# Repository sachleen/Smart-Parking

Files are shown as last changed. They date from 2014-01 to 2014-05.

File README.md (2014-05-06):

Smart Parking ([GitHub][1])
=============

A system to monitor parking space availability and help drivers quickly find a nearby place to park.

[California State University, Sacramento][2]

Computer Engineering Senior Design Project

Team #4

 - Sachleen Sandhu
 - Caleb Fountain
 - Phillip Booker

  [1]: https://github.com/sachleen/Smart-Parking
  [2]: http://csus.edu

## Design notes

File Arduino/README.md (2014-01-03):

Base
====

Base station is responsible for communicating data from the wireless nodes to the web server

Node
====

Each wireless node connects up to 32 parking sensors. The node transmits the status of the sensors to the base.

Sensor
======

A parking sensor detects the presence of a vehicle and sends its status to the node.

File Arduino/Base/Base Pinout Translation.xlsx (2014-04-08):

Pin Names | AKA | Arduino Chip Pins | Arduino SMT Pins | Connected to Base Station Code
Reset |  | 1 | 29 | RST(PropPlug, I2C)
(RXD)PD0 | Digital Pin 0 (RX) | 2 | 30 | TX(PropPlug)
(TXD)PD1 | Digital Pin 1 (TX) | 3 | 31 | RX(PropPlug)
(INT0)PD2 | Digital Pin 2 | 4 | 32 | SIM900_PWR
(INT1)PD3 | Digital Pin 3 | 5 | 1 | SIM900_RST
(T0)PD4 | Digital Pin 4 | 6 | 2 | XBEE_DTR(Sleep Pin)
VCC |  | 7 | 4,6 | VCC from MCP73833 Charing Chip
GND |  | 8 | 3,5 | Regular GND
XTAL1 |  | 9 | 7 | Resonator
XTAL2 |  | 10 | 8 | Resonator
(T1)PD5 | Digital Pin 5 | 11 | 9 | XBEE_DOUT
(AIN0)PD6 | Digital Pin 6 | 12 | 10 | XBEE_DIN
(AIN1)PD7 | Digital Pin 7 | 13 | 11 | SIM900_RX
(ICP)PB0 | Digital Pin 8 | 14 | 12 | SIM900_TX
(OC1)PB1 | Digital Pin 9 | 15 | 13
(SS)PB2 | Digital Pin 10 | 16 | 14
(MOSI)PB3 | Digital Pin 11 | 17 | 15 | I2C(MOSI)
(MISO)PB4 | Digital Pin 12 | 18 | 16 | I2C(MISO)
(SCK)PB5 | Digital Pin 13 | 19 | 17 | I2C(SCK)
AVCC |  | 20 | 18 | VCC from MCP73833 Charing Chip
AREF |  | 21 | 20 | VCC from MCP73833 Charing Chip
AGND |  | 22 | 21 | Regular GND
(ADC0)PC0 | Analog Input 0 | 23 | 23
(ADC1)PC1 | Analog Input 1 | 24 | 24
(ADC2)PC2 | Analog Input 2 | 25 | 25
(ADC3)PC3 | Analog Input 3 | 26 | 26
(ADC4)PC4 | Analog Input 4 | 27 | 27
(ADC5)PC5 | Analog Input 5 | 28 | 28
ADC6 | Analog Input 6 |  | 19
ADC7 | Analog Input 7 |  | 22

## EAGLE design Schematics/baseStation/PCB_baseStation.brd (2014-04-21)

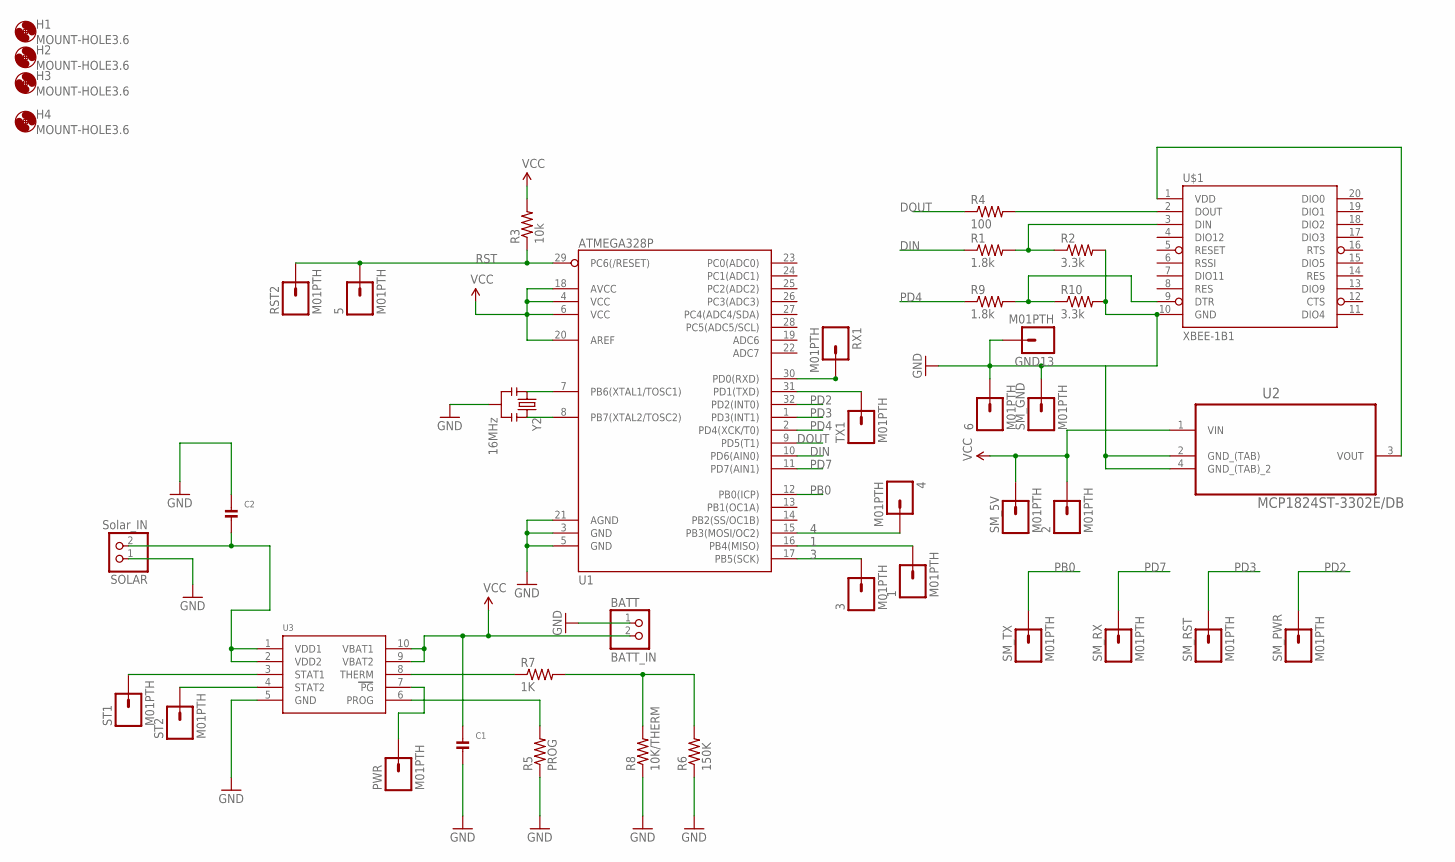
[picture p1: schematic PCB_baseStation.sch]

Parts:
1, 2, 3, 4, 5, 6: M01PTH; 1X01
BATT: BATT_IN; JSTPH2
C1, C2: CAP_CERAMIC0805; 0805
GND13: M01PTH; 1X01
H1, H2, H3, H4: MOUNT-HOLE3.6; 3,6
PWR: M01PTH; 1X01
R1, R9: 1.8k; 0603-RES
R2, R10: 3.3k; 0603-RES
R3: 10k; 1206
R4: 100; 0603-RES
R5: PROG; 0805-THM
R6: 150K; M0805
R7: 1K; M0805
R8: 10K/THERM; 0805-THM
RST2: M01PTH; 1X01
RX1: M01PTH; 1X01
SM_5V: M01PTH; 1X01
SM_GND: M01PTH; 1X01
SM_PWR: M01PTH; 1X01
SM_RST: M01PTH; 1X01
SM_RX: M01PTH; 1X01
SM_TX: M01PTH; 1X01
SOLAR: Solar_IN; JSTPH2
ST1, ST2: M01PTH; 1X01
TX1: M01PTH; 1X01
U1: ATMEGA328P; TQFP32-08
U2: MCP1824ST-3302E/DB; SOT230P700X180-4N
U3: MCP73833; MSOP10
U$1: XBEE-1B1; XBEE-1
Y2: 16MHz; RESONATOR-SMD

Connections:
1: 1.1, U1.16 (PB4(MISO))
3: 3.1, U1.17 (PB5(SCK))
4: 4.1, U1.15 (PB3(MOSI/OC2))
DIN: R1.1, U1.10 (PD6(AIN0))
DOUT: R4.1, U1.9 (PD5(T1))
GND: 6.1, BATT.1, C1.2, C2.1, GND13.1, R2.2, R5.1, R6.1, R8.1, R10.2, SM_GND.1, SOLAR.1, U1.3 (GND), U1.5 (GND), U1.21 (AGND), U2.2 (GND_(TAB)), U2.4 (GND_(TAB)_2), U3.5 (GND), U$1.10 (GND), Y2.2
unnamed: ST1.1, U3.3 (STAT1)
unnamed: ST2.1, U3.4 (STAT2)
unnamed: R1.2, R2.1, U$1.3 (DIN)
unnamed: R4.2, U$1.2 (DOUT)
unnamed: R9.2, R10.1, U$1.9 (DTR)
unnamed: U1.7 (PB6(XTAL1/TOSC1)), Y2.1
unnamed: U1.8 (PB7(XTAL2/TOSC2)), Y2.3
unnamed: C2.2, SOLAR.2, U3.1 (VDD1), U3.2 (VDD2)
unnamed: R5.2, U3.6 (PROG)
unnamed: PWR.1, U3.7 (PG)
unnamed: R6.2, R7.2, R8.2
unnamed: U2.3 (VOUT), U$1.1 (VDD)
unnamed: R7.1, U3.8 (THERM)
unnamed: TX1.1, U1.31 (PD1(TXD))
unnamed: RX1.1, U1.30 (PD0(RXD))
PB0: SM_TX.1, U1.12 (PB0(ICP))
PD2: SM_PWR.1, U1.32 (PD2(INT0))
PD3: SM_RST.1, U1.1 (PD3(INT1))
PD4: R9.1, U1.2 (PD4(XCK/T0))
PD7: SM_RX.1, U1.11 (PD7(AIN1))
RST: 5.1, R3.1, RST2.1, U1.29 (PC6(/RESET))
VCC: 2.1, BATT.2, C1.1, R3.2, SM_5V.1, U1.4 (VCC), U1.6 (VCC), U1.18 (AVCC), U1.20 (AREF), U2.1 (VIN), U3.9 (VBAT2), U3.10 (VBAT1)

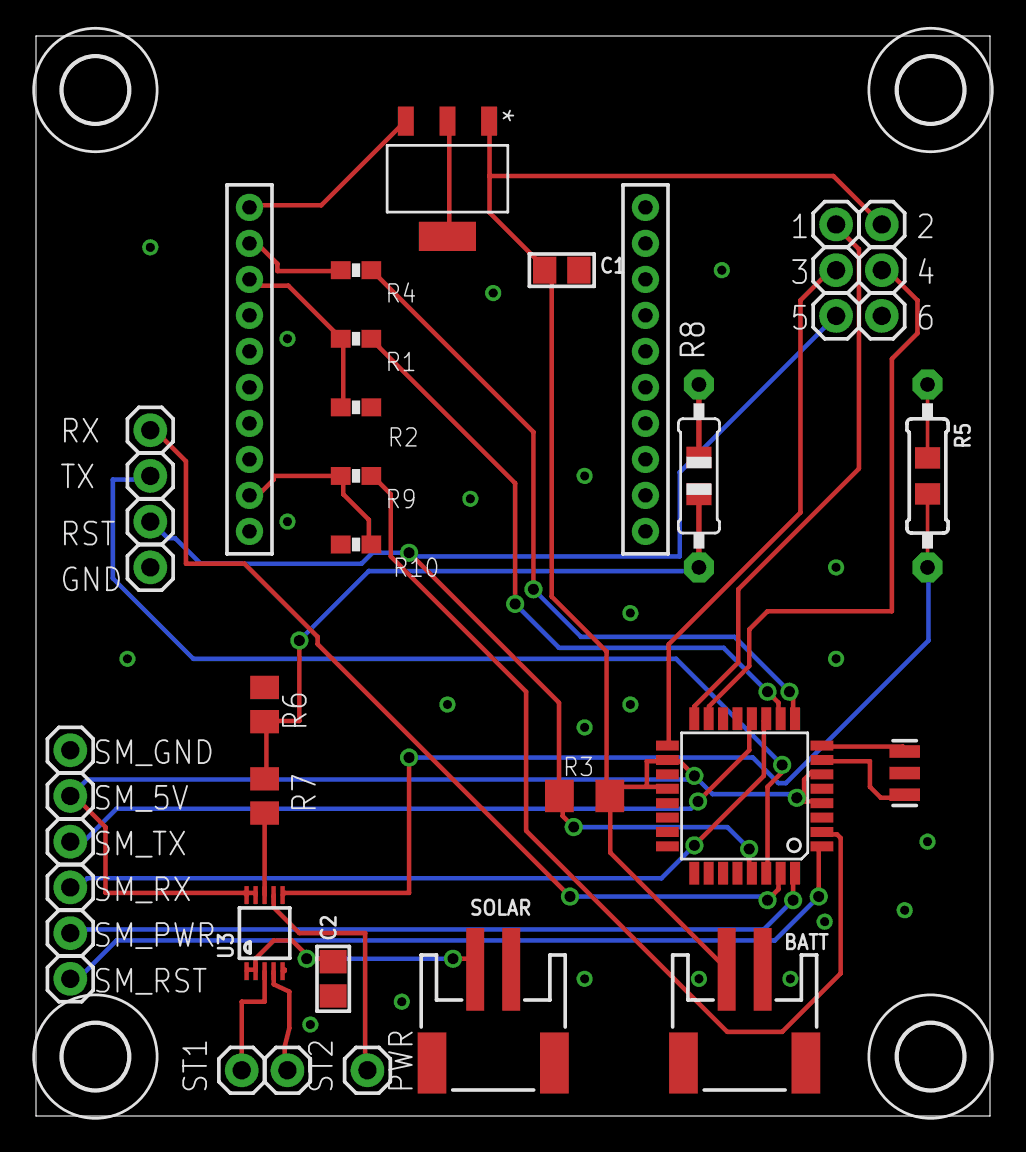
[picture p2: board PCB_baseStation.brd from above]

Board: 2 copper layers, 53.0 x 60.0 mm, 42 parts (0 on the bottom side), 28 nets.

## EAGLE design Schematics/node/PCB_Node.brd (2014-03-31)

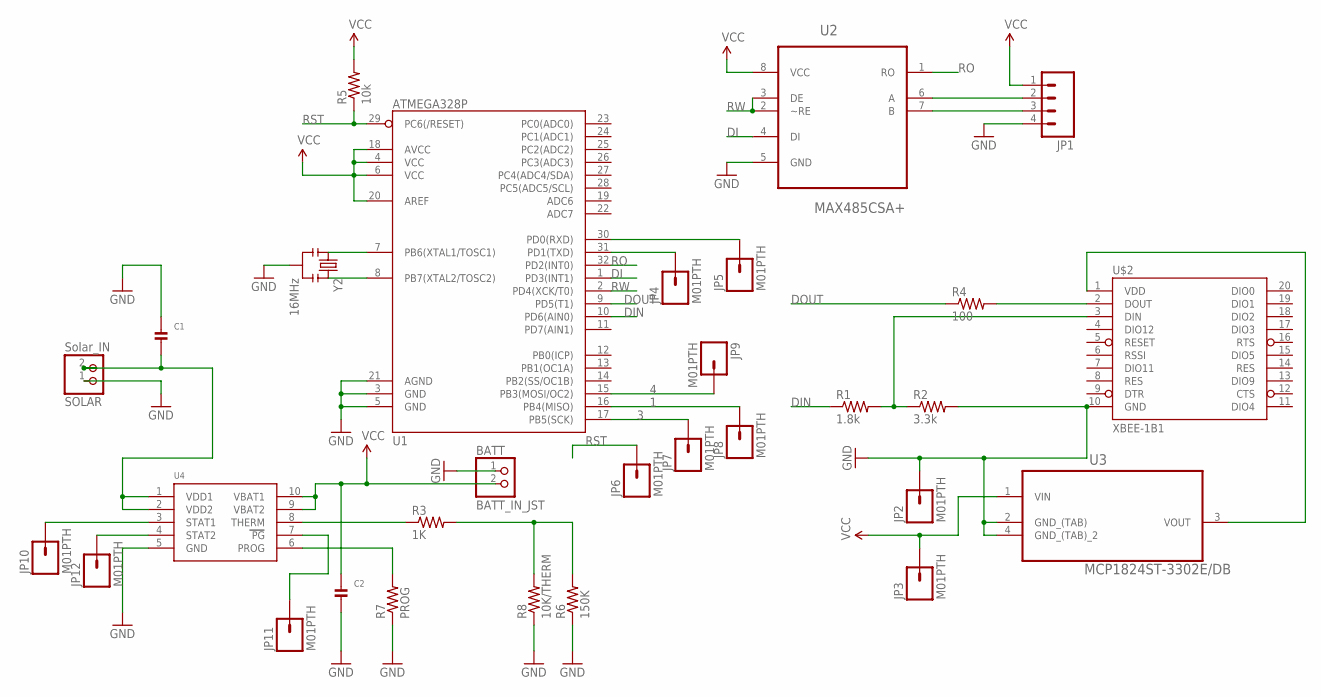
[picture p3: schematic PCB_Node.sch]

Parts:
BATT: BATT_IN_JST; JSTPH2
C1, C2: CAP_CERAMIC0805; 0805
JP1: M04PTH; 1X04
JP2, JP3, JP4, JP5, JP6, JP7, JP8, JP9, JP10, JP11, JP12: M01PTH; 1X01
R1: 1.8k; 0603-RES
R2: 3.3k; 0603-RES
R3: 1K; R0805
R4: 100; 0603-RES
R5: 10k; 0603-RES
R6: 150K; R0805
R7: PROG; 0805-THM
R8: 10K/THERM; 0805-THM
SOLAR: Solar_IN; JSTPH2
U1: ATMEGA328P; TQFP32-08
U2: MAX485CSA+; SOIC127P600X175-8N
U3: MCP1824ST-3302E/DB; SOT230P700X180-4N
U4: MCP73833; MSOP10
U$2: XBEE-1B1; XBEE-1
Y2: 16MHz; RESONATOR-SMD

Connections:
1: JP8.1, U1.16 (PB4(MISO))
3: JP7.1, U1.17 (PB5(SCK))
4: JP9.1, U1.15 (PB3(MOSI/OC2))
DI: U1.1 (PD3(INT1)), U2.4 (DI)
DIN: R1.1, U1.10 (PD6(AIN0))
DOUT: R4.1, U1.9 (PD5(T1))
GND: BATT.1, C1.1, C2.2, JP1.4, JP2.1, R2.2, R6.1, R7.1, R8.1, SOLAR.1, U1.3 (GND), U1.5 (GND), U1.21 (AGND), U2.5 (GND), U3.2 (GND_(TAB)), U3.4 (GND_(TAB)_2), U4.5 (GND), U$2.10 (GND), Y2.2
unnamed: R4.2, U$2.2 (DOUT)
unnamed: R1.2, R2.1, U$2.3 (DIN)
unnamed: R7.2, U4.6 (PROG)
unnamed: U3.3 (VOUT), U$2.1 (VDD)
unnamed: R3.1, U4.8 (THERM)
unnamed: R3.2, R6.2, R8.2
unnamed: C1.2, SOLAR.2, U4.1 (VDD1), U4.2 (VDD2)
unnamed: JP10.1, U4.3 (STAT1)
unnamed: JP12.1, U4.4 (STAT2)
unnamed: JP11.1, U4.7 (PG)
unnamed: U1.8 (PB7(XTAL2/TOSC2)), Y2.3
unnamed: U1.7 (PB6(XTAL1/TOSC1)), Y2.1
unnamed: JP4.1, U1.31 (PD1(TXD))
unnamed: JP5.1, U1.30 (PD0(RXD))
unnamed: JP1.2, U2.6 (A)
unnamed: JP1.3, U2.7 (B)
RO: U1.32 (PD2(INT0)), U2.1 (RO)
RST: JP6.1, R5.1, U1.29 (PC6(/RESET))
RW: U1.2 (PD4(XCK/T0)), U2.2 (~RE), U2.3 (DE)
VCC: BATT.2, C2.1, JP1.1, JP3.1, R5.2, U1.4 (VCC), U1.6 (VCC), U1.18 (AVCC), U1.20 (AREF), U2.8 (VCC), U3.1 (VIN), U4.9 (VBAT2), U4.10 (VBAT1)

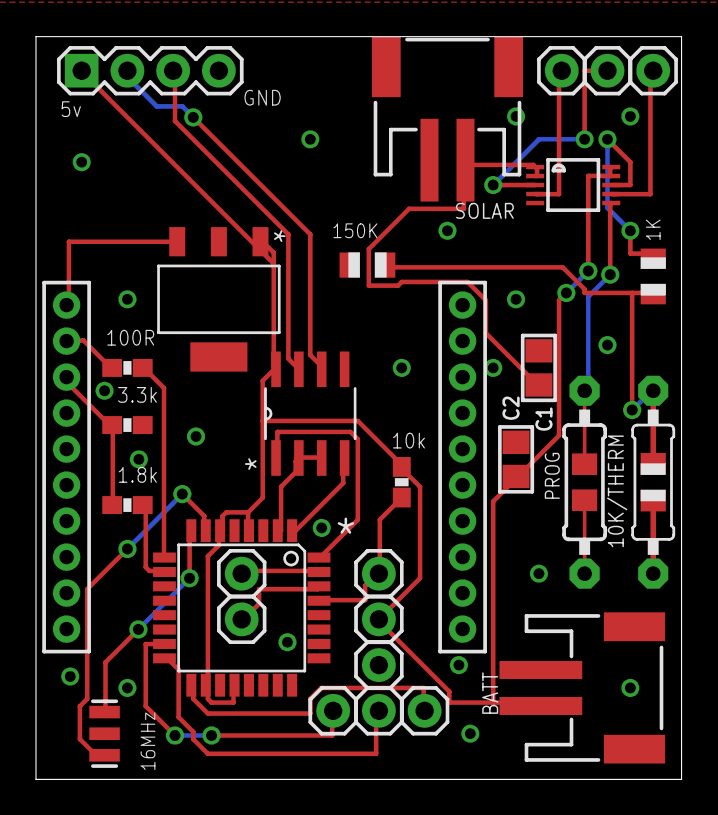
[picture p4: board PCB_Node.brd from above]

Board: 2 copper layers, 35.9 x 41.3 mm, 30 parts (0 on the bottom side), 27 nets.

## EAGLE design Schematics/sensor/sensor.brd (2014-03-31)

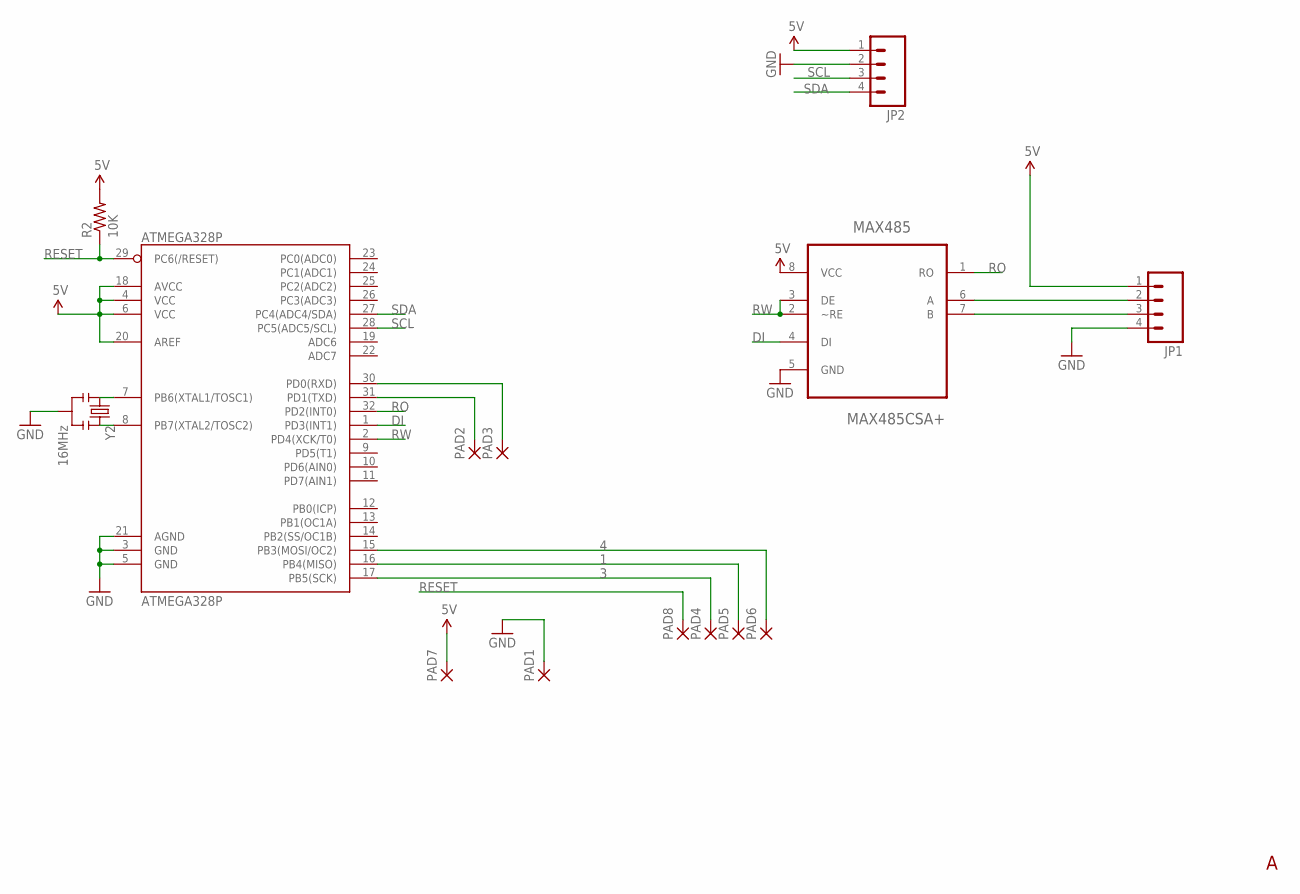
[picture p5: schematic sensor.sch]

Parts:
ATMEGA328P: ATMEGA328P; TQFP32-08
JP1, JP2: M04PTH; 1X04
MAX485: MAX485CSA+; SOIC127P600X175-8N
PAD1, PAD2, PAD3, PAD4, PAD5, PAD6, PAD7, PAD8: 1,6/0,9
R2: 10K; 0603-RES
Y2: 16MHz; RESONATOR-SMD

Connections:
1: ATMEGA328P.16 (PB4(MISO)), PAD5.1
3: ATMEGA328P.17 (PB5(SCK)), PAD4.1
4: ATMEGA328P.15 (PB3(MOSI/OC2)), PAD6.1
5V: ATMEGA328P.4 (VCC), ATMEGA328P.6 (VCC), ATMEGA328P.18 (AVCC), ATMEGA328P.20 (AREF), JP1.1, JP2.1, MAX485.8 (VCC), PAD7.1, R2.2
DI: ATMEGA328P.1 (PD3(INT1)), MAX485.4 (DI)
GND: ATMEGA328P.3 (GND), ATMEGA328P.5 (GND), ATMEGA328P.21 (AGND), JP1.4, JP2.2, MAX485.5 (GND), PAD1.1, Y2.2
unnamed: ATMEGA328P.7 (PB6(XTAL1/TOSC1)), Y2.1
unnamed: ATMEGA328P.8 (PB7(XTAL2/TOSC2)), Y2.3
unnamed: ATMEGA328P.30 (PD0(RXD)), PAD3.1
unnamed: JP1.2, MAX485.6 (A)
unnamed: JP1.3, MAX485.7 (B)
unnamed: ATMEGA328P.31 (PD1(TXD)), PAD2.1
RESET: ATMEGA328P.29 (PC6(/RESET)), PAD8.1, R2.1
RO: ATMEGA328P.32 (PD2(INT0)), MAX485.1 (RO)
RW: ATMEGA328P.2 (PD4(XCK/T0)), MAX485.2 (~RE), MAX485.3 (DE)
SCL: ATMEGA328P.28 (PC5(ADC5/SCL)), JP2.3
SDA: ATMEGA328P.27 (PC4(ADC4/SDA)), JP2.4

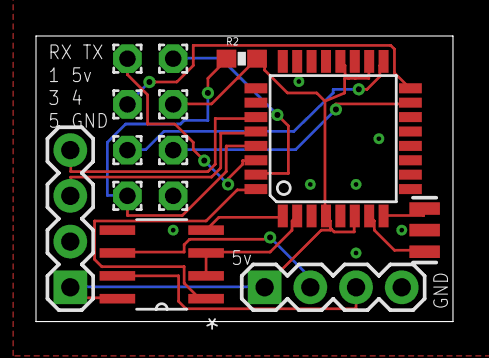
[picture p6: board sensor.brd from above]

Board: 2 copper layers, 23.2 x 15.9 mm, 14 parts (0 on the bottom side), 17 nets.

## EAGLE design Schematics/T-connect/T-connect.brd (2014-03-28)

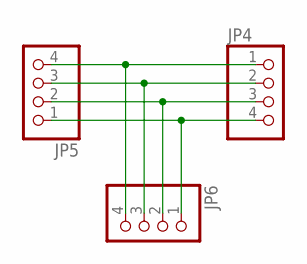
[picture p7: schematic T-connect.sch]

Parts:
JP4, JP5, JP6: PINHD-1X4/90; 1X04/90

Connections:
unnamed: JP4.1, JP5.4, JP6.4
unnamed: JP4.2, JP5.3, JP6.3
unnamed: JP4.3, JP5.2, JP6.2
unnamed: JP4.4, JP5.1, JP6.1

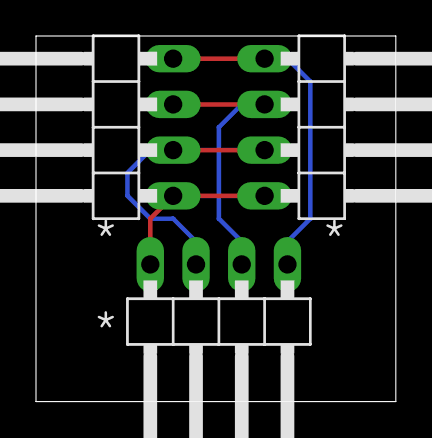
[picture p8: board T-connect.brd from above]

Board: 2 copper layers, 20.0 x 20.3 mm, 3 parts (0 on the bottom side), 4 nets.

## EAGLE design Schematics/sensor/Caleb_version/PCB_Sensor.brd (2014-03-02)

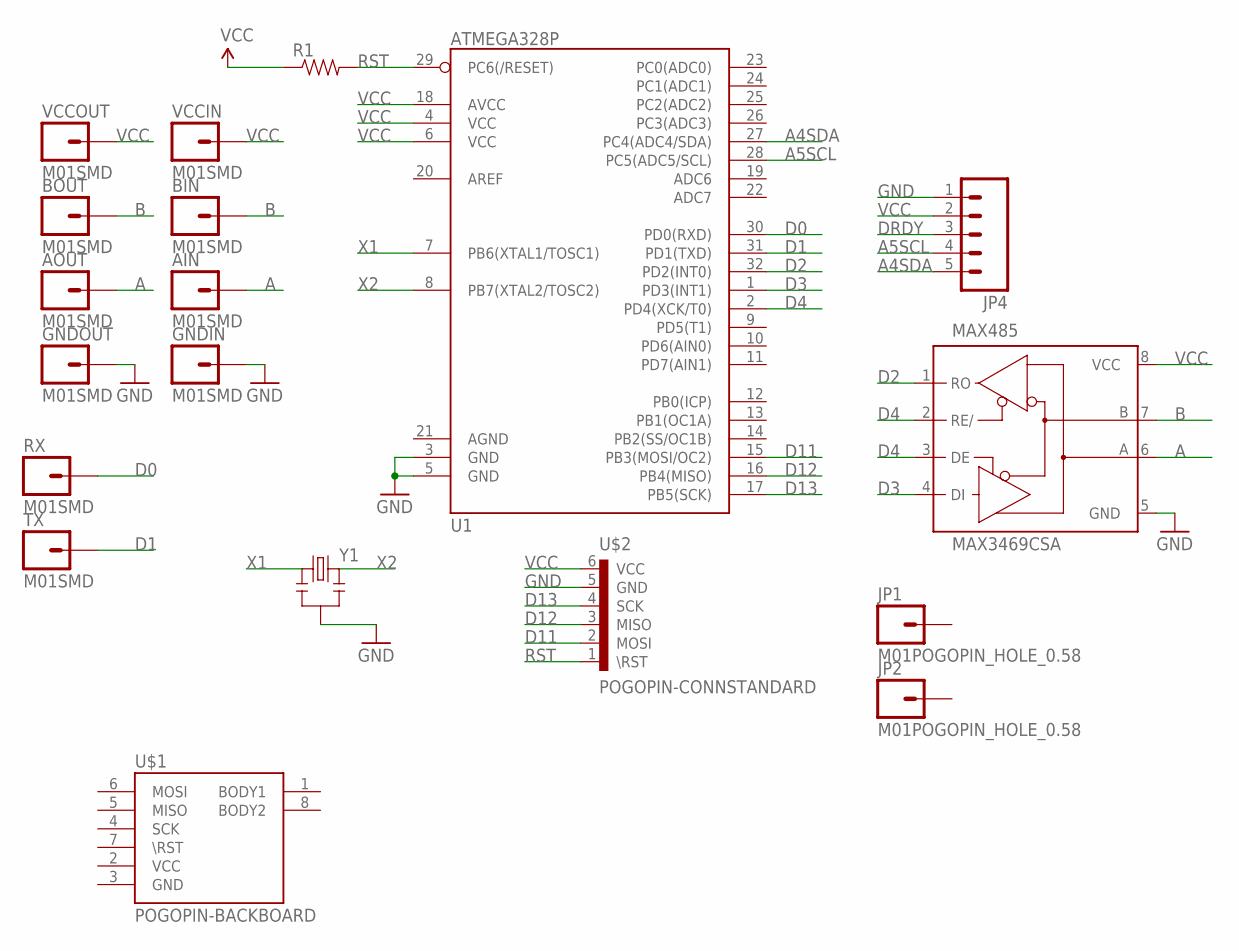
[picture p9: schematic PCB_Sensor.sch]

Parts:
AIN: M01SMD; LUXEON-PAD
AOUT: M01SMD; LUXEON-PAD
BIN: M01SMD; LUXEON-PAD
BOUT: M01SMD; LUXEON-PAD
GNDIN: M01SMD; LUXEON-PAD
GNDOUT: M01SMD; LUXEON-PAD
JP1, JP2: M01POGOPIN_HOLE_0.58; 1X01_POGOPIN_HOLE_0.58
JP4: M05PTH; 1X05
MAX485: MAX3469CSA; SO08
R1: RESISTOR1206; 1206
RX: M01SMD; LUXEON-PAD
TX: M01SMD; LUXEON-PAD
U1: ATMEGA328P; TQFP32-08
U$1: POGOPIN-BACKBOARD; POGOPROG-BACKMOUNT
U$2: POGOPIN-CONNSTANDARD; POGOPROG-CONN
VCCIN: M01SMD; LUXEON-PAD
VCCOUT: M01SMD; LUXEON-PAD
Y1: RESONATORPTH; RESONATOR-PTH

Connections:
A: AIN.P$1, MAX485.6 (A)
A4SDA: JP4.5, U1.27 (PC4(ADC4/SDA))
A5SCL: JP4.4, U1.28 (PC5(ADC5/SCL))
B: BIN.P$1, MAX485.7 (B)
D0: U1.30 (PD0(RXD))
D1: U1.31 (PD1(TXD))
D2: MAX485.1 (RO), U1.32 (PD2(INT0))
D3: MAX485.4 (DI), U1.1 (PD3(INT1))
D4: MAX485.2 (RE/), MAX485.3 (DE), U1.2 (PD4(XCK/T0))
D11: U1.15 (PB3(MOSI/OC2)), U$2.2 (MOSI)
D12: U1.16 (PB4(MISO)), U$2.3 (MISO)
D13: U1.17 (PB5(SCK)), U$2.4 (SCK)
DRDY: JP4.3
GND: GNDIN.P$1, JP4.1, MAX485.5 (GND), U1.3 (GND), U1.5 (GND), U$2.5 (GND), Y1.2
RST: R1.2, U1.29 (PC6(/RESET)), U$2.1 (\RST)
VCC: JP4.2, MAX485.8 (VCC), R1.1, U1.4 (VCC), U1.6 (VCC), U1.18 (AVCC), U$2.6 (VCC), VCCIN.P$1, VCCOUT.P$1
X1: U1.7 (PB6(XTAL1/TOSC1)), Y1.1
X2: U1.8 (PB7(XTAL2/TOSC2)), Y1.3

Board: 2 copper layers, 19 parts (0 on the bottom side), 15 nets, no tracks yet.

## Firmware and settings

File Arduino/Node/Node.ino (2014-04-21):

#define DEBUG_ENABLED
#include <RS485.h>
#include <SoftwareSerial.h>

#include <avr/sleep.h>
#include <avr/power.h>
#include <avr/wdt.h>

#include "globals.h"
#include "WiredCommunication.h"
#include "XBeeCommunication.h"

#define XBEE_SLEEP 7	//Set Sleep pin to D7

#define MAX_SENSORS 32
#define SENSOR_MAX 10
String baseId = "00000";

volatile int f_wdt=1;//used for wdt interrupt
volatile int sleep_count = 0;

SoftwareSerial xbee(5, 6); // RX, TX
//SoftwareSerial xbee(2, 3); //Testing with Xbee only

WiredCommunication wiredbus;
XBeeCommunication xcomm("TEST1");//Change here for different nodes


int  numSensors = -1; // Starts off at -1 to show the Node has yet to be intialized
int retryCount = 0;//retry count for adding messages to queue
int check = 0;//checks for success of adding to queue
String messageFromBase = "";


char sensorStatus[MAX_SENSORS]; // keeps track of status of each sensor
bool dataChanged = false; // Set to true if any sensor's status has changed. XBee only sends if this is true.
bool sendOk = false;
bool sensorSuccess = false;
int sendCount;

int sensorCount = 0;

/*
    Setup block
    Initializes communication protocols and initiates other setup related tasks.
*/
void setup()
{
  DEBUG_INIT(9600);
  DEBUG_PRINTLN("New System Startup - Sender");

  xbee.begin(9600);
  power_adc_disable();
  power_spi_disable();
  //power_timer0_disable(); need timer 0 for delay()
  power_timer1_disable();
  power_timer2_disable();
  power_twi_disable();
  wdtSetup();
  // Wait for sensors to power up and calibrate
  delay(2000);
  
  DEBUG_PRINTLN(numSensors); delay(2000);
  String response = "";
  pinMode(XBEE_SLEEP, OUTPUT);   // sleep control
  digitalWrite(XBEE_SLEEP, LOW);   // deassert 
  
  // Need this delay for XBee to "warm up" ... messages aren't being received faster than this.
  for (int i = 0; i < 10; i++) {
   DEBUG_PRINT(".");
   delay(1000);
  }
  setXbeeSleep();
  
  /**
   * The node will stay in this loop until it receives it's number of sensors from the Base station
   * Commented out for testing purposes
   */
   
  while(numSensors < 0){
    xbee.println("Sending...");
    xcomm.sendMessage(baseId, "N");//"N" indicates that the Node is requesting its number of Sensors
    response = xcomm.getMessage();

    if(response != NULL){
      uint8_t start = 0;
      uint8_t end = response.indexOf(',');
    
      start = end + 1;
      end = response.indexOf(',', start);
      String numberResponse = response.substring(start, end);
  
      numberResponse.trim();
      numSensors = numberResponse.toInt();
      DEBUG_PRINTLN(numSensors);
    }
  }
  
    
  //numSensors = 3;//used when we don't get numSensors from Base Station
  
  /**
   * This while loop will run until the number of nodes the sensor has assigned a new ID matches numSensors
   * The loop keeps track of how many assignment statements reached the sensors successfully
   */
   
  while(!sensorSuccess){  
    for(int i=1; i <= SENSOR_MAX; i++){
      char sendBuff[maxMsgLen+2];
      sendBuff[0] = getSensorIdFromIndex(i);//get sensorIdFromIndex
      sendBuff[1] = 'P';
      sendBuff[2] = getSensorIdFromIndex(sensorCount+1);
      sendBuff[3] = '\0';
      wiredbus.sendMessage("wakeup");//to wake up sensors
      if(wiredbus.sendMessage(sendBuff)){
        DEBUG_PRINTLN(sendBuff);
        // Listen for response
        char recBuff[maxMsgLen+3+1];
        timeout_init(2000);
        bool gotResponse = false;
        while (!timeout_timedout()) {
          if (wiredbus.getMessage(recBuff)){
            DEBUG_PRINT("Got:");
            DEBUG_PRINTLN(recBuff);
            if (recBuff[0] == getSensorIdFromIndex(i)) {
              if(recBuff[1] == 'X'){
                sensorCount++;
                DEBUG_PRINT("Sensor Assigned: ");
                DEBUG_PRINTLN(sensorCount);//Sensor count
              }
            }
	    else {
              // Wrong sensor ID
              DEBUG_PRINTLN("Wrong sensor responded to assignment...");
            }
            gotResponse = true;
            break;
          }
          delay(100);
        }
        if (!gotResponse) {
          DEBUG_PRINTLN("Timed out!");
        }
      }
      else {
        DEBUG_PRINTLN("Assignment Failed");
      }
      if((sensorCount) == numSensors)
        break;
      delay(500);
    }
    if((sensorCount) < numSensors){
      sensorSuccess = false;
      DEBUG_PRINTLN("Sensors intialization failed");
      sensorCount = 0;
      resetSensors();//This tells sensors to randomize to a new SensorID
    }
    else{
      sensorSuccess = true;
      DEBUG_PRINTLN("Sensors initialized");
      delay(3000);
    }
  }
  
}

void loop()
{
    if(f_wdt == 1){
      Serial.println("Awake");//Check to see if Arduino woke back up
    }
	
    /*
        Loops through all the sensors asking for a status.
        Records the responses or time outs in sensorStatus[]
    */
    for (int sensorNum = 1; sensorNum <= numSensors; sensorNum++) {
        
        DEBUG_PRINT("Querying Sensor ");DEBUG_PRINTLN(sensorNum);
        
        // Send some data to the sensors to wake them up. Doesn't matter what it is.
        //wiredbus.sendMessage("wakeup");
        
        //The message is composed of a sensor ID and command.
        char sendBuff[maxMsgLen+1];
        sendBuff[0] = getSensorIdFromIndex(sensorNum);//get sensorIdFromIndex
        sendBuff[1] = 'C';
        sendBuff[2] = '\0';
        
        wiredbus.sendMessage("wakeup");
        if(wiredbus.sendMessage(sendBuff))
        {
            DEBUG_PRINTLN(sendBuff);
            
            // Listen for response
            char recBuff[maxMsgLen+3+1];
            timeout_init(2000);
            bool gotResponse = false;
            while (!timeout_timedout()) {
              
                if (wiredbus.getMessage(recBuff)){
                    
                    DEBUG_PRINT("Got:");
                    DEBUG_PRINTLN(recBuff);
                    
                    /*
                        If the response is from the same sensor we responded data from, parse it.
                    */
                    if (recBuff[0] == getSensorIdFromIndex(sensorNum)) {
                        switch (recBuff[1]) {
                            case 'T': // Car present
                                DEBUG_PRINTLN("CAR PRESENT");
                                if (sensorStatus[sensorNum-1] != 'T'){
                                    sensorStatus[sensorNum-1] = 'T';
                                    dataChanged = true;
                                }
                                break;
                            case 'A': // Car NOT present
                                DEBUG_PRINTLN("CAR NOT PRESENT");
                                if (sensorStatus[sensorNum-1] != 'A'){
                                    sensorStatus[sensorNum-1] = 'A';
                                    dataChanged = true;
                                }
                                break;
                            default:
                                DEBUG_PRINTLN("Invalid Response");
                                sensorStatus[sensorNum-1] = 'I';
                        }
                    } else {
                        // Wrong sensor ID
                        DEBUG_PRINTLN("Wrong sensor responded to request...");
                        sensorStatus[sensorNum-1] = 'W';
                    }
                    
                    gotResponse = true;
                    break;
                }
                delay(100);
            }
            
            if (!gotResponse) {
                DEBUG_PRINTLN("Timed out!");
                sensorStatus[sensorNum-1] = 'L';
            }
        }
	else {
            DEBUG_PRINTLN("Send Failed");
        }
        DEBUG_PRINTLN();
        delay(500);
    }
    
    
    /*
        Print stuff out to serial
    */
    DEBUG_PRINTLN("==============================");
    DEBUG_PRINT("Sensor: ");
    for (int i = 1; i <= numSensors; i++) {
        DEBUG_PRINT(i);
        DEBUG_PRINT(" ");
    }
    DEBUG_PRINT("\nStatus: ");
    for (int i = 1; i <= numSensors; i++) {
        DEBUG_PRINT(sensorStatus[i-1]);
        DEBUG_PRINT((i < 10) ? " " : "  ");
    }
    DEBUG_PRINTLN();
    
    DEBUG_PRINTLN(dataChanged ? "Data changed, sending..." : "Not sending. no change");
    //dataChanged = true;//This line will force the XBee to send a message. (Used for testing)
    if(!sendOk)
        dataChanged = true;
    if (dataChanged) {
        digitalWrite(XBEE_SLEEP, LOW);
        /*
            Send data to base station using XBee
        */
        // Get count of available spots
        uint8_t countAvailable = 0;
        for (int i = 1; i <= numSensors; i++) {
            if (sensorStatus[i-1] == 'A') {
                countAvailable++;
            }
        }
        
        /*
            Prepare XBee message packet:
            [Message Identifier],[Available Spots]
        */
		String updateMessage = "U," + String(countAvailable);//The identifier "U" means that this is an update meant for the server
                xcomm.sendMessage(baseId, updateMessage);
		String response = xcomm.getMessage();
		sendCount = 0;
		while (response == NULL && sendCount < 4){//Send attempts bumped up to 4 in case it sends during update loop
			xcomm.sendMessage(baseId, updateMessage);
			response = xcomm.getMessage();
			sendCount++;
		}
		if(response!=NULL){
			uint8_t start = 0;
			uint8_t end = response.indexOf(',');
			
			String baseCheck = response.substring(end+1);
			if (baseCheck.indexOf("OK") < 0){
				DEBUG_PRINTLN("Didn't receive correct message from base");
                                sendOk = false;
			}
			else{
				DEBUG_PRINTLN("Update Successful");
                                sendOk = true;
			}
		}
		else{
			DEBUG_PRINTLN("Update Failed");
                        sendOk = false;
		}
    }
    
    DEBUG_PRINTLN("==============================\n");
    
    
	digitalWrite(XBEE_SLEEP, HIGH);//Set XBee to sleep
    
    dataChanged = false;//reset dataChanged flag
    
    /**
    *This block of code will cause the arduino to sleep for a given number of minutes
    *It is commented out for demonstration purposes where we want a quick response
    */
	 
    /*
    Serial.println("Going to sleep");
    delay(100);
    
    int cyclesSlept = 0;
    int sleepMinutes = 1;//Minutes we want arduino to sleep
    int sleepCycles = (sleepMinutes * 60)/8;//This tells us how many sleep cycles of 8 seconds to perform
    
    
    while(cyclesSlept < sleepCycles){
      f_wdt = 0;
      wdt_reset();//Resets the watchdog timer for the sleep cycle
      enterSleep();
      cyclesSlept++;
    }
    */
}

char getSensorIdFromIndex(uint8_t index) {
    // Returns a byte from 0x40 of the ascii table. Starting at @ a b c ...
    // Have to do this because if we start from 0 1 2... the control characters at the beginning mess up transmissions
    // Since sensor 0 is master, it will be @, the slaves will start from a
    return (char)(index + 96);
}

// Timeout Functions
// ========================================
unsigned long _timeout_end = 0;

void timeout_init(int timeoutms) {
    _timeout_end = millis() + timeoutms;
}
unsigned long timeout_remaining() {
    return _timeout_end-millis();
}
bool timeout_timedout() {
    return millis() > _timeout_end;
}

/**
 * This method issues the AT command SM1 to the XBee
 * This sets the XBee Sleep Mode to 1 which allows us to control the sleep state of the XBee by asserting a its DTR pin
 */
void setXbeeSleep(){
	String ok_response = "OK\r"; // the response we expect.
	xbee.print("+++");
	xbee.listen();
	//xbee.print("+++");
	String content = "";
	int counter = 0;
	while(!xbee.available() && counter < 500) {
		counter++;
		delay(10);
	}

	if (counter >= 500) {
		Serial.println(F("XBEE Timed Out"));
	}

	while (xbee.available()) {
		char input = xbee.read();
		content.concat(input);
		if (input == '\n') {
			break;
		}
		delay(1);
	}
	//Serial.print("Content: ");

	//Serial.println(content);

	if (content.equals(ok_response)) {
		xbee.println("ATSM 1");
	delay(500);
		xbee.println("ATCN");     // back to data mode
		Serial.println(F("Set to pin sleep"));
	}
}

void wdtSetup(){
	/* Clear the reset flag. */
	MCUSR &= ~(1<<WDRF);

	/* In order to change WDE or the prescaler, we need to
	* set WDCE (This will allow updates for 4 clock cycles).
	*/
	WDTCSR |= (1<<WDCE) | (1<<WDE);

	/* set new watchdog timeout prescaler value */
	WDTCSR = 1<<WDP0 | 1<<WDP3; /* 8.0 seconds */

	/* Enable the WD interrupt (note no reset). */
	WDTCSR |= _BV(WDIE);

	Serial.println("Initialisation complete.");
	delay(100); //Allow for serial print to complete.
}

ISR(WDT_vect)
{
  if(f_wdt == 0)
  {
    f_wdt=1;
  }
  else
  {
    //Serial.println("WDT Overrun!!!");
  }
}

void enterSleep(void)
{
  set_sleep_mode(SLEEP_MODE_PWR_DOWN);   /* EDIT: could also use SLEEP_MODE_PWR_DOWN for lowest power consumption. */
  sleep_enable();
  
  /* Now enter sleep mode. */
  sleep_mode();
  
  /* The program will continue from here after the WDT timeout*/
  sleep_disable(); /* First thing to do is disable sleep. */
  
  /* Re-enable the peripherals. */
  //power_all_enable();
}

void initializeSensors(){//Will add initializing code here once I'm sure it works after another test
  
}

/**
 *This method sends a message to all attached sensors letting them know to randomize their SensorIDs
 */
void resetSensors(){
  for(int i=1; i <= SENSOR_MAX; i++){
    char sendBuff[maxMsgLen+1];
    if(i == 5)
      sendBuff[0] = 'e';
    else
    sendBuff[0] = getSensorIdFromIndex(i);//get sensorIdFromIndex
    sendBuff[1] = 'R';
    sendBuff[2] = '\0';
    wiredbus.sendMessage("wakeup");//to wake up sensors
    if(wiredbus.sendMessage(sendBuff)){
      DEBUG_PRINTLN(sendBuff);
      // Listen for response
      char recBuff[maxMsgLen+3+1];
      timeout_init(2000);
      bool gotResponse = false;
      while (!timeout_timedout()) {
        if (wiredbus.getMessage(recBuff)){
          DEBUG_PRINT("Got:");
          DEBUG_PRINTLN(recBuff);
          if (recBuff[0] == getSensorIdFromIndex(i)) {
            if(recBuff[1] == 'Y'){
              DEBUG_PRINT("Sensor Randomized: ");
              DEBUG_PRINTLN(i);//Sensor count
            }
          } else {
            // Wrong sensor ID
            DEBUG_PRINTLN("Wrong sensor responded to assignment...");
          }
          gotResponse = true;
          break;
        }
        delay(100);
      }
        if (!gotResponse) {
          DEBUG_PRINTLN("Timed out!");
        }
    }
  	else {
  		DEBUG_PRINTLN("Randomize Failed");
  	}
  	delay(500);
  }
    
}

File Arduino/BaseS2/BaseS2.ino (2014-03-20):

#include <avr/wdt.h> // for watchdog timer
#include <SoftwareSerial.h>

#define SIM900_BAUD 2400
#define XBEE_BAUD 9600
#define QMAX 10

SoftwareSerial SIM900(7, 8);
SoftwareSerial xbee(2, 3);
//SoftwareSerial xbee(5, 6);//For Testing on Node board


String response = ""; // Holds the response from SIM900
String messageFromNode = "";
String apiKey = "e1d1b85eef174d89121da2407f7bb15b";
bool pass = false; // Keeps track of various phases of the connection. Must be set to true during each phase for success

//These values were used for testing

int val1 = 0;
int val2 = 0;
int button = 0;
String test = "1";
String amountToSend = "";

//Keeps track of the number of messages to be sent to the server
int qCount = 0;

//These arrays are what hold the different parts of the messages to be sent to the server
String nodeIds[QMAX];
int spacesAvail[QMAX];
int totalSpaces[QMAX];

int sendResponse;//this holds the response from the sendRequestServer()


void setup()
{
  Serial.begin(9600);
  SIM900.begin(SIM900_BAUD);// Communicates with Server
  powerSIM900();
  connectToNetwork();
  xbee.begin(XBEE_BAUD); // Communicates with node
  timeout_init(5000);//Starts timer for updates to be sent to server
}

void loop(){
  Serial.println(F("====================Beginning of Void Loop===================="));
  
  /*
  This limits the sending of updates to the server by sending a maximum of 10 once every minute
  or once the array of requests reaches its maximum
  */
  if(timeout_timedout() || qCount == QMAX){
    if(qCount > 0){//will only send if q isn't empty
      Serial.print(F("Made it to server update. Number of messages: "));
      Serial.println(qCount);
      delay(1000);
      for(int i = 0; i < qCount; i++){
        sendResponse = sendRequestServer(nodeIds[i], 'U', spacesAvail[i], totalSpaces[i]);//Sends a message to the server to update the status of the node
		if(sendResponse == 1){
			Serial.println("Update " + (String)i + " Succeeded");
		}
		else{
			Serial.println("Update " + (String)i + " Failed");
		}
      }
      qCount = 0;
    }
    timeout_init(5000);
  }
  
  //TODO - Replace with getNodeMessage()
  messageFromNode = getNodeMessage();
  /*
  xbee.listen();
  messageFromNode = xbeeResponse();
  Serial.println("Message From Node: "+ messageFromNode);
  */
  
  if (messageFromNode != NULL) {
        uint8_t start = 0;
        uint8_t end = messageFromNode.indexOf(',');
        String nodeId = messageFromNode.substring(start, end);
        
        start = end + 1;
        end = messageFromNode.indexOf(',', start);
        uint8_t total = messageFromNode.substring(start, end).toInt();
        
        start = end + 1;
        end = messageFromNode.indexOf(',', start);
        uint8_t available = messageFromNode.substring(start, end).toInt();
        
        Serial.println("Node:  " + String(nodeId));
        Serial.println("Total: " + String(total));
        Serial.println("Avail: " + String(available));
        delay(2000);
        /*
		Can use other numbers above 32 for different cases
		At power-on, Node will have 99 set as number of sensors so that it knows to ask server for number
		*/
        if(total == 99){
			int numSensors = sendRequestServer(nodeId, 'N', 0, 0);
			//sendMessageNode(nodeId, 3);//Using this for testing
                        sendMessageNode(nodeId, numSensors);
        }
        else{
          //We add the NodeId, Total, and available to their respective arrays to send later
          nodeIds[qCount] = nodeId;
          totalSpaces[qCount] = total;
          spacesAvail[qCount] = available;
          qCount++;
        }
    }
    Serial.println(F("====================End of Void Loop===================="));
    Serial.print("Free Ram after loop: ");Serial.println(freeRam());
}

/*
    Power on sequence
    Holds pin 9 (power button) high for 2 seconds to toggle device power.
    NOTE: this toggles the power and works under the assumption that the module is initially OFF.
*/
void powerSIM900() {
    Serial.println(F("Toggling Power"));
    pinMode(9, OUTPUT);
    digitalWrite(9,LOW);
    delay(1000);
    digitalWrite(9,HIGH);
    delay(2000);
    digitalWrite(9,LOW);
    delay(1000);
    Serial.println(F("Done"));
}

int sendRequestServer(String nodeId, char identifierC, int amount, int total){
		int nodeNumber = -1;
                
                uint8_t responseStart;
                uint8_t responseEnd;
                uint8_t quoteStart;
                uint8_t quoteEnd;
                
                String responseTotal;
                String quoteCheck;
                
		switch(identifierC){
			case 'N':
                                /*
				Serial.print("Sending Number of Sensors Request from : ");
				Serial.println(nodeId);
				nodeNumber = 3;//Will be replaced with response from server
				break;
                                */
				
				Serial.print("Sending Number of Sensors Request from : ");
				Serial.println(nodeId);
				//Sending update to server
				SIM900.listen();
				// Set the bearer profile identifier to 1 (see bearer initialization in connectToNetwork() phase 4)
				SIM900.println(F("AT+HTTPPARA=\"CID\",\"1\""));
				response = sim900Response();
				if (response.indexOf("OK") < 0) {
					Serial.println(F("Error setting CID"));
					Serial.println(response);
				}
				
				// Set the URL
				Serial.println(F("Setting URL"));
				
				SIM900.println("AT+HTTPPARA=\"URL\",\"http://sachleen.com/sachleen/parking/API/nodes/" + String(nodeId) + "\"");
				response = sim900Response();
				Serial.println("HTTP RESPONSE IS: " + response);

				
				if (response.indexOf("OK") >= 0) {
					Serial.println(F("Set URL"));
					pass = true;
				}
				
				if (pass) {
					pass = false;
					
					// Set the action to GET
					Serial.println(F("Making HTTP Request"));
					
					SIM900.println(F("AT+HTTPACTION=0"));
					response = sim900Response();
						
					// Check for not only an OK but also a 200 status code.
					if (response.indexOf("OK") >= 0) {
						Serial.println(F("Made request!"));
						pass = true;
					} else {
						response = sim900Response();
						Serial.println(response);
					}
				}
				
				if (pass) {
					// Read response from server. By not providing any parameters, it reads all data.
					Serial.println(F("Reading HTTP response data"));
					
					SIM900.println(F("AT+HTTPREAD"));
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

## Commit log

2014-01-06 Opens device's Maps app when clicking on marker
2014-01-07 Added current location marker
2014-01-07 Handled case where zooming in/out was not triggering new data load
2014-01-07 Made dev/prod mode switching easier.
2014-02-02 Sensor schematics and board layouts
    [sensor.brd, sensor.sch]
2014-02-02 Changed headers for 485 bus and added more labels.
    [sensor.brd, sensor.sch]
2014-02-08 Made sensor PCB smaller. Removed through hole circuit.
    [sensor.brd, sensor.sch]
2014-02-09 Top/bottom ground planes weren't connected. Added via to connect them.
    [sensor.brd]
2014-02-17 RX and TX for PROPPLUG weren't connected. they are now.
    [sensor.brd, sensor.sch]
2014-02-22 * Updated api key privileges - combined create_or_update with delete. * convert node ID to upper case before storing it in database.
2014-03-02 Connector changed
    I changed connectors to the following
    Device: M01SMD (M01)
    Package: LUXEON-PAD
    Library: SparkFun-Connectors
    [PCB_Sensor.brd, PCB_Sensor.sch]
2014-03-02 Revision by Caleb
    Changed programming connectors to be on the surface as pads only for
    programming with another board.
    Rearranged the board to minimize the size as much as possible.
    Dimensions are .95 x .65
    [PCB_Sensor.brd, PCB_Sensor.sch, sensor.brd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]
2014-03-02 PCB Node
    Created schematic and board layout for Node PCB
    [PCB_Node.brd, PCB_Node.sch]
2014-03-15 Added my current code for Base and Node
2014-03-20 Cleaned up sensor code, split up main code from RS485 code. Added debug functions instead of Searial.println
2014-03-21 Converted wired communication stuff to a class.
2014-03-21 Changed all Serial prints to DEBUG. Integrated with WiredCommunication class.
2014-03-21 PCB updates
    changed sensor PCB to 3.0
    changed Node PCB to 2.0 and parts list to go with it (Sach, can you
    look over the schematic, board, and parts list that I have so far to
    make sure I have everything correct?)
    added Base Station PCB 0.5
    [PCB_Node.brd, PCB_Node.sch, PCB_baseStation.sch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]
2014-03-21 Corrected Node PCB issues found by Sachleen for version 2.0
    [PCB_Node.brd, PCB_Node.sch]
2014-03-22 Moved RS485 initialization into WiredCommunication class.
2014-03-22 Include globals in WiredCommunications to allow for debug prints
2014-03-23 add debug prints in xbee class. add xbee class to base
2014-03-23 Node Fixes
    Made fixes to Node PCB.
    - connected solar power to charging chip
    - made power to battery and atmega from charging chip only
    - rearranged board for these changes to work
    [PCB_Node.brd, PCB_Node.sch]
2014-03-25 Node fixes
    Corrected the c1 capacitor connected to solar power correctly
    moved part names to locations where they will be read because of vias
    blocking them
    [PCB_Node.brd, PCB_Node.sch]
2014-03-29 Fixed bug where xbee and simcomm wouldn't work together. needed to switch between software serial devices.
    [Base.ino, SIMCommunication.cpp]
2014-03-30 Trying to cut Base code
2014-03-30 Cut out N case
2014-03-30 Reverted to old code to test (left working one in comments)
    [Base.ino]
2014-03-30 Reverting to what worked after failed attempts...
    [Base.ino, Node.ino]
2014-03-31 PCB improvements
    Node_SP 2.0: moved some text to the back layer
    Sen_SP 4.0: improved the board for programming and changed the
    resonator from through hole to surface mount - then rearranged the
    items on the board to make it smaller
    [PCB_Node.brd, sensor.brd, sensor.sch]
2014-03-31 Power optimizations in sensor.
2014-04-02 Toggles power when it needs to send updates to the server
2014-04-02 compass sleep mode. saves about 0.1mA
2014-04-04 Base Station PCB 1.0
    Finished Base Station PCB design version 1.0
    [PCB_baseStation.brd, PCB_baseStation.sch]
2014-04-06 Added Xbee and arduino sleep to Node
2014-04-06 Base Station PCB improvements
    Base_SP 1.1
    moved prop plug and ISP closer in
    added two resistors to limit voltage from arduino to xbee pin 9(SLP)
    [PCB_baseStation.brd, PCB_baseStation.sch]
2014-04-06 Base Station PCB Improvements
    Base_SP 1.2
    moved components around to group them better
    corrected xbee pin 9 to be connected from arduino PD4 to PD7
    [PCB_baseStation.brd, PCB_baseStation.sch]
2014-04-07 Base Station PCB Improvements
    Base_SP 1.3
    fixed SIM900 pins that go to Arduino
    changed xbee pin that goes to Arduino
    created table of base Arduino pins and where they go to
    [Base Pinout Translation.xlsx, PCB_baseStation.brd, PCB_baseStation.sch]
2014-04-07 Revert 84d25af..6e9f095
    This rolls back to commit 84d25afdcd8c89c582355f2af172ebeae3c02958.
    [PCB_baseStation.brd, PCB_baseStation.sch]
2014-04-07 Revert f17e3e6..3ebf404
    This rolls back to commit f17e3e6aa3351730fd70c4ce41f61063c92e8cc4.
    [Base Pinout Translation.xlsx, PCB_baseStation.brd, PCB_baseStation.sch]
2014-04-07 Revert 6e9f095..8a23197
    This rolls back to commit 6e9f095d9700ac4f46dd20743e80d1823ffcaa8e.
    [Base Pinout Translation.xlsx, PCB_baseStation.brd, PCB_baseStation.sch]
2014-04-08 Revert f17e3e6..f513072
    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
    [Base Pinout Translation.xlsx, PCB_baseStation.brd, PCB_baseStation.sch]
2014-04-08 PCB Base Station Improvements
    Base_SP 1.4
    fixed issues that were occurring with code
    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
    [Base Pinout Translation.xlsx, PCB_baseStation.brd, PCB_baseStation.sch]
2014-04-11 Node and Sensor code that randomly assigns Sensor ID at Node startup
2014-04-14 Fixed Sensor Issues
2014-04-14 Fixed Network connect issue when sending updates
    [Base.ino, Node.ino]
2014-04-21 Base Station PCB Improvements
    Base_SP 1.5
    - Fix: connected Regulator for XBee to GND
    [PCB_baseStation.brd, PCB_baseStation.sch]
2014-04-21 Code used for deployable prototype day
2014-04-21 Base Station PCB update
    Updated the version of the board that is printed on the back from 1.4
    to 1.5
    [PCB_baseStation.brd]

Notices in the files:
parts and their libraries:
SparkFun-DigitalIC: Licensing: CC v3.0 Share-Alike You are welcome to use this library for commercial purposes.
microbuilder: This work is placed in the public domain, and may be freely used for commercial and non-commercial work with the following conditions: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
